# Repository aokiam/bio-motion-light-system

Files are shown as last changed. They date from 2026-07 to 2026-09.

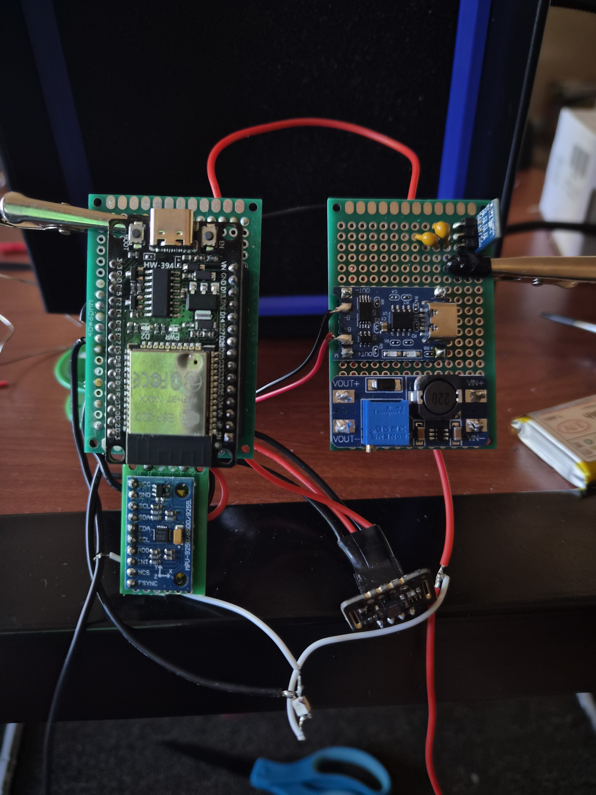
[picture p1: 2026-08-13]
hardware/images/hardware-components.jpg

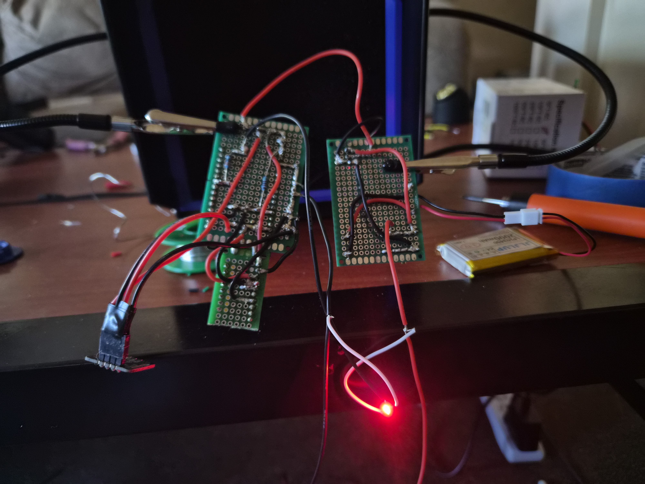
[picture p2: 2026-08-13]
hardware/images/proof-of-concept.jpg

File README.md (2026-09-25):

# BioMotion Light System
An ESP32-based wearable embedded system that visualizes physiological and motion data using addressable LEDs. The system combines heart-rate sensing, inertial measurement, Bluetooth Low Energy (BLE), and real-time LED animation to create adaptive lighting effects.

## Status
**COMPLETE**

## Features
- ESP32-WROOM-32D firmware
- BLE companion app
- Heart-rate reactive LEDs
- Motion-reactive animations
- WS2812B addressable LEDs
- Real-time sensor processing
- Modular hardware architecture

## Hardware
### Core Components
| Component | Purpose |
|---|---|
| ESP32-WROOM-32D | Main microcontroller |
| MAX30102 | Optical heart rate sensor |
| MPU6500 | 6-axis IMU |
| WS2812B LEDs | Addressable LED lighting |
| USB-C Power Bank | Portable power for ESP32 |

## Software Architecture
The firmware is organized into independent modules to simplify development and future expansion.
```
Main Loop
|
|--- Sensor Manager
|--- BLE Manager
|--- Settings Manager
|--- State Machine
|--- Animation Engine
|--- LED Driver
```

### Responsibilities
- **Sensor Manager** - Reads heart-rate and IMU data
- **BLE Manager** - Handles communication with the mobile app
- **Settings Manager** - Stores user preferences
- **State Machine** - Controls device operating modes
- **Animation Engine** - Generates LED effects from sensor data
- **LED Driver** - Updates the WS2812B LEDs

## Demo

## BOM
| Component | Quantity | Link |
|---|---|---|
| ESP32-WROOM-32D | 1 | [Amazon](amazon.com/gp/product/B0CR5Y2JVD/ref=ox_sc_saved_title_1?smid=A2Z10KY0342329&psc=1) / [Aliexpress](https://www.aliexpress.us/item/3256808317516268.html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)
| MAX30102 | 1 | [Amazon](https://www.amazon.com/AEDIKO-MAX30102-Detection-Concentration-Compatible/dp/B09LQDW27N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) / [Aliexpress](https://www.aliexpress.us/item/3256806829092762.html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)
| MPU6500 | 1 | [Amazon](https://www.amazon.com/QCCAN-GY-6500-MPU-6500-Gyroscope-Accelerometer/dp/B0B74QXZS8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) / [Aliexpress](https://www.aliexpress.us/item/3256807106311918.html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)
| WS2812B LEDs | 1 | [Amazon](https://www.amazon.com/dp/B088FJF9XD?ref=ppx_yo2ov_dt_b_fed_asin_title)
| USB-C Power Bank | 1 | [Amazon](https://www.amazon.com/dp/B0C6XK77HJ?ref=ppx_yo2ov_dt_b_fed_asin_title&th=1)
| Capacitors | Various | [Amazon](https://www.amazon.com/dp/B094HRK8QX?th=1)
| Resistors | Various | [Amazon](amazon.com/BOJACK-Values-Resistor-Resistors-Assortment/dp/B08FD1XVL6/ref=sr_1_3?crid=11U68YXQ4GGL9&dib=eyJ2IjoiMSJ9.ZA9QUhgtnvrS43dsRj2R0Cgy41Nr97HX9SyGDpZDWpPWZZPgmlStloE5j-S4aVRzhNzVbHujwhh2rykXNWfSwWtxrdj0LjP2nuBT9WeIb1yrirSbLG2rh23-9O-s8JNNv8sogRjmW4ZHQmak2ZAvcZmQZiUZCB9a84dqvmNuLrD1v7yqO8pJ9xzG38eocl9LCAgt32m8WE6QjvAYi8n43Y5nB8lfalTQB03mP4tsoRA.vj05dTqYUgw8NiO9xexmNOf0Y1FdqwWJqsNqr4UUW60&dib_tag=se&keywords=resistor+kit&qid=1784245899&sprefix=resistor+kit%2Caps%2C369&sr=8-3)
| Perfboard | 2 40x60mm and 1 20x80mm | [Amazon](amazon.com/dp/B0BWCFH57N?ref=ppx_yo2ov_dt_b_fed_asin_title)

## Future Work
- Custom PCB design
- Mobile app expansion
- Multiple synchronized systems

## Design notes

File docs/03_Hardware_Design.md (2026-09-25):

# Hardware Design
## Overview
The hardware consists of a rechargable power bank, an ESP32 microcontroller, two sensors, and an addressable LED strip.

---
## Main Components
| Component | Purpose |
|---|---|
| ESP32-WROOM-32D | Main Controller |
| MAX30102 | Heart rate sensing |
| MPU6500 | Motion sensing |
| WS2812B LEDs | Lighting |
<<<<<<< HEAD
| Power Bank | Portable power |
=======
| TP4056 | Battery charging |
| MT3608 | 5V boost converter |
| AMS 1117 | 3.3V regulator |
| LiPo Battery | Portable power |
>>>>>>> 4d88ec08d6901f317757a8ecc8b70e3ebece8073

---
## Power Architecture
```
USB-C Power Bank
  |
ESP32 USB-C Port
  | +5V
     |----- LED Strip
  | +3.3V
     |----- Sensors
```
---
## Sensor Connections
### MAX30102
- SDA -> ESP32 SDA
- SCL -> ESP32 SCL
- 3.3V
- GND

### MPU6500
- SDA -> ESP32 SDA
- SCL -> ESP32 SCL
- 3.3V
- GND

Both sensors share the same I2C bus.

---
## LED Interface
The WS2812B LED strip is driven using a single GPIO pin.

---
## Design Considerations
- Separate 5V and 3.3V rails
- Common ground throughout system
- Decoupling capacitors near every IC
- Thermal considerations during high LED brightness

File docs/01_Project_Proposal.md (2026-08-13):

# Project Proposal
## Project Title
BioMotion Light System
## Author
Allyson Aoki

---
## Overview
The BioMotion Light System is an ESP32-based embedded platform that creates dynamic LED lighting effects based on physiological and motion data. The system monitors the wearer's heart rate using a MAX30102 optical sensor and body movement using an MPU6500 inertial measurement unit (IMU). These inputs are processed in real time to generate responsive lighting animations on an addressable WS2812B LED strip.

A Bluetooth Low Energy (BLE) interface allows users to configure brightness, animation modes, color themes, and sensor sensitivity through a mobile application.

The project combines embedded firmware, power electronics, sensor integration, wireless communication, and wearable system design into a single portable platform.

---
## Objectives
### Functional Objectives
- Read heart rate continually
- Detect user movement
- Generate responsive LED animations
- Support BLE configuration
- Operate from rechargable battery power

### Educational Objectives
- Embedded firmware architecture
- I2C sensor integration
- BLE communication
- Real-time scheduling
- Power management
- Wearable electronics design

--- 
## Motivation
One of my hobbies includes cosplay, and this is planned to be implemented into a homemade cosplay headpiece. Traditional cosplay lighting systems operate generally using predefined animation sequences with limited interaction. This project explores context-aware wearable electronics that react naturally to the user's physical state, producing immersive lighting effects while remaining lightweight and portable.

---
## Expected Deliverables
- Functional embedded firmware
- Working hardware prototype
- BLE companion application
- Hardware documentation
- Wiring diagrams
- Testing documentation
- GitHub repository

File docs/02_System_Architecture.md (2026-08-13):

# System Architecture
## Overview
The system consitis of five primary subsystems:
1. Power System
2. Embedded Controller
3. Sensors
4. LED Output
5. Bluetooth Interface

```
Power Bank
    |
ESP32 3.3V Rail
 |--- MAX30102
 |--- MPU6500
 |--- BLE
 |--- WS2812B
ESP32 VIN (5V) Rail
 |--- LED Strip
```
---
## Data Flow
Heart Rate Sensor -> Sensor Manager -> State Machine -> Animation Engine -> LED Driver -> WS2812B LEDs

The IMU follows the same processing pipeline and contributes additional movement information used by the animation engine.

---
## Communication Interfaces
| Device | Interface |
|---|---|
| MAX30102 | I2C |
| MPU6500 | I2C |
| Mobile App | BLE |
| WS2812B LEDs | Single-wire data|

---
## Timing Requirements
| Task | Frequency |
|---|---|
| Heart Rate | 25Hz |
| IMU | 100 Hz |
| LED Refresh | 60 FPS |
| BLE Updates | <100 ms |

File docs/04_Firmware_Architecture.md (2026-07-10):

# Firmware Architecture
## Overview
The firmware follows a modular architecture that separates hardware drivers from application logic.
```
Main Loop
|
|--- Sensor Manager
|
|--- BLE Manager
| 
|--- Settings Manager
|
|--- State Machine
|
|--- Animation Engine
|
|--- LED Driver
```
## Modules
### Sensor Manager
Responsibilities:
- Read MAX30102
- Read MPU6500
- Filter noise measurements
- Store latest sensor values

---
### BLE Manager
Responsibilities:
- Handle BLE advertising
- Pair with phone
- Receive user settings
- Update configuration

---
### Settings Manager
Stores:
- Brightness
- Color palette
- Motion sensitivity
- Heart-rate sensitivity
- Animation mode

---
### State Machine
Controls operating modes:
- Idle
- Active
- High Motion
- Elevated Heart Rate
- Sleep

Transitions occur based on sensor thresholds

---
### Animation Engine
Uses:
- Heart rate
- Motion data
- User settings

Outputs LED frames at 60 FPS.

---
### LED Driver
Responsibilities:
- Convert animation buffer
- Send pixel data
- Maintain frame timing

--- 
### Main Execution Loop
1. Read sensors
2. Process BLE packets
3. Update state machine
4. Generate animation frame
5. Send LEDs
6. Repeat

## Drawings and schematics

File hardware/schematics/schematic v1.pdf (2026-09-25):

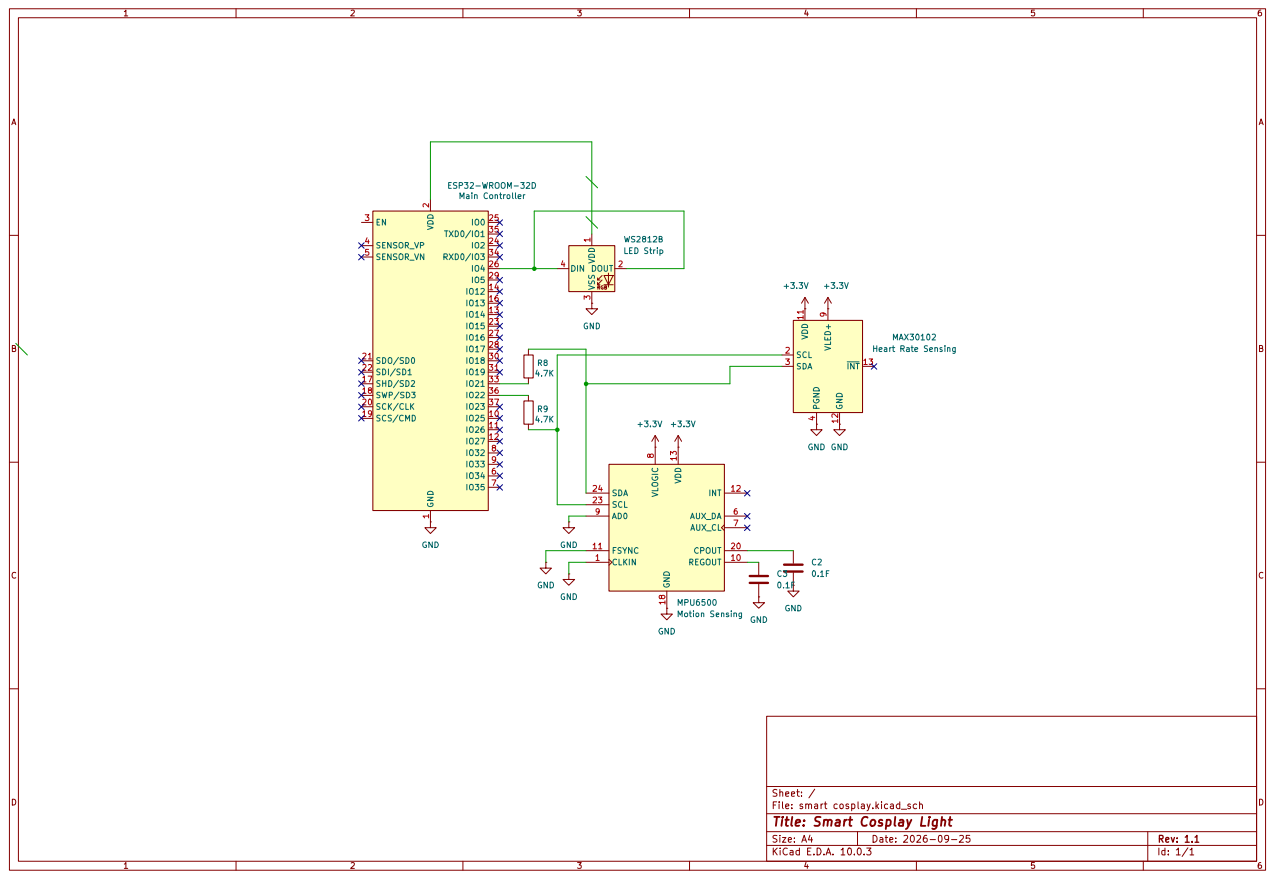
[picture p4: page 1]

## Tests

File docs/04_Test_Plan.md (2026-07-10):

# Test Plan
## Objectives
Verify that each subsystem functions independently before validating complete system integration.

---
# Unit Testing
## Heart Rate Sensor
### Procedure
Measure heart rate while resting and compare with a commercial smartwatch

**Expected error:** ±5 BPM

**Pass Criteria:** Measurements remain within tolerance

---
## IMU
Test Cases:
- Stationary
- Walking
- Quick slash
- Quick rotation

Verify acceleration and angular velocity change appropriately.

---
## LED Driver
Verify:
- All LEDs illuminate
- No flickering
- Correct colors
- Smooth animation

---
## BLE
Measure:
- Connection time
- Response latency
- Packet reliability

Target:
Settings update within 100ms.

---
# Integration Testing
Verify:

Heart rate changes -> Animation changes

Movement -> Animation changes

BLE command -> Immediate LED response

---
# Battery Testing
Measure:
- Runtime at 25%
- Runtime at 50%
- Runtime at 100%

Monitor battery voltage throughout discharge.

---
# Stress Testing
Operate continuously for:
- 30 minutes
- 1 hour
- 2 hours

Verify:
- No crashes
- Stable BLE communication
- No overheating
- Consistent sensor readings

---
# Acceptance criteria
The project is considered complete if:
- Heart rate is detected reliably
- Motion is detected accurately
- BLE communication remains stable
- LED animations remain smooth
- Battery operates safely
- System run continuously for at least two hours

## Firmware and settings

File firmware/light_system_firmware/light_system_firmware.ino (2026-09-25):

#include <Wire.h>
#include <Adafruit_NeoPixel.h>
#include "MAX30105.h"
#include "heartRate.h"
#include <BLEDevice.h>
#include <BLEServer.h>
#include <BLEUtils.h>
#include <BLE2902.h>

// PIN config
#define SDA_PIN 21
#define SCL_PIN 22
#define LED_PIN 26
#define NUM_LEDS 25

const int MPU_ADDR = 0x68;
MAX30105 particleSensor;
Adafruit_NeoPixel strip(NUM_LEDS, LED_PIN, NEO_GRB + NEO_KHZ800);

// BLE UUIDS -----------  ***match with App.jsx***
#define SERVICE_UUID            "4fafc201-1fb5-459e-8fcc-c5c9c331914b"
#define BRIGHTNESS_CHAR_UUID    "beb5483e-36e1-4688-b7f5-ea07361b26a8"
#define ANIM_MODE_CHAR_UUID     "0a3b0f1e-6b0a-4a6a-9a3a-3e6b1a2c4d5e"
#define HEART_RATE_CHAR_UUID    "6b3f1a4c-2d5e-4f6a-8b9c-1a2b3c4d5e6f"
#define COLOR_CHAR_UUID         "9c1e2f3a-4b5c-4d6e-8f7a-1b2c3d4e5f6a"
#define HR_INPUT_CHAR_UUID      "2d3e4f5a-6b7c-4d8e-9f0a-1b2c3d4e5f6b"
#define MOTION_INPUT_CHAR_UUID  "5a6b7c8d-9e0f-4a1b-8c2d-3e4f5a6b7c8d"
#define MOTION_STATE_CHAR_UUID  "3bddb61d-67dc-40e0-9da9-bc49426116e9"

BLECharacteristic *brightnessChar;
BLECharacteristic *animModeChar;
BLECharacteristic *heartRateChar;
BLECharacteristic *colorChar;
BLECharacteristic *hrInputChar;
BLECharacteristic *motionInputChar;
BLECharacteristic *motionStateChar;

bool deviceConnected = false;

// live settings; what the BLE callbacks actually change
enum AnimMode { MODE_STATIC, MODE_PULSE, MODE_SLASH, MODE_DYNAMIC };
AnimMode currentAnimMode = MODE_STATIC;

uint8_t globalBrightness = 128;
uint32_t activeColor = 0x00BFFF;
bool heartRateInputEnabled = false;
bool motionInputEnabled = false;

// heart rate detection state
const byte RATE_SIZE = 4;
byte rates[RATE_SIZE];
byte rateSpot = 0;
long lastBeat = 0;
int beatAvg = 0;
bool fingerPresent = false;

// LED state machine
enum LedState { IDLE_OFF, SEARCHING, BPM_PULSE, SLASH_ANIM, STATIC_ON };
LedState currentState = IDLE_OFF;
LedState stateBeforeSlash = IDLE_OFF;

// slash detection
float GYRO_SLASH_THRESHOLD = 300.0; //  units = deg/s
unsigned long lastSlashTime = 0;
const unsigned long SLASH_COOLDOWN = 800;

unsigned long slashStartTime = 0;
const unsigned long SLASH_STEP_MS = 40;
const unsigned long SLASH_TRAIL_MS = 1000;

// walking vs. idle detection
float motionEMA = 0.0;
const float MOTION_EMA_ALPHA = 0.2;
const float WALK_ENTER_THRESHOLD = 40.0;
const float WALK_EXIT_THRESHOLD = 20.0;
bool isWalking = false;

// ----------------- MPU6500 helpers ------------------
bool mpuPresent() {
  Wire.beginTransmission(MPU_ADDR);
  return (Wire.endTransmission() == 0);
}

void mpuWake() {
  Wire.beginTransmission(MPU_ADDR);
  Wire.write(0x6B);
  Wire.write(0x00);
  Wire.endTransmission();
}

void mpuReadGyro(float &gxd, float &gyd, float &gzd) {
  Wire.beginTransmission(MPU_ADDR);
  Wire.write(0x43);
  Wire.endTransmission(false);
  Wire.requestFrom(MPU_ADDR, 6, true);

  int16_t gx = Wire.read() << 8 | Wire.read();
  int16_t gy = Wire.read() << 8 | Wire.read();
  int16_t gz = Wire.read() << 8 | Wire.read();

  gxd = gx / 131.0;
  gyd = gy / 131.0;
  gzd = gz / 131.0;
}

bool checkForSlash() {
  float gx, gy, gz;
  mpuReadGyro(gx, gy, gz);
  float magnitude = sqrt(gx * gx + gy * gy + gz * gz);

  if (magnitude > GYRO_SLASH_THRESHOLD && millis() - lastSlashTime > SLASH_COOLDOWN) {
    lastSlashTime = millis();
    return true;
  }
  return false;
}

void updateWalkingState() {
  float gx, gy, gz;
  mpuReadGyro(gx, gy, gz);
  float magnitude = sqrt(gx * gx + gy * gy + gz * gz);

  motionEMA = (MOTION_EMA_ALPHA * magnitude) + ((1.0 - MOTION_EMA_ALPHA) * motionEMA);

  bool wasWalking = isWalking;
  if (!isWalking && motionEMA > WALK_ENTER_THRESHOLD) {
    isWalking = true;
  } else if (isWalking && motionEMA < WALK_EXIT_THRESHOLD) {
    isWalking = false;
  }

  if (isWalking != wasWalking && deviceConnected) {
    uint8_t stateByte = isWalking ? 1 : 0;
    motionStateChar->setValue(&stateByte, 1);
    motionStateChar->notify();
    Serial.print("[MOTION STATE] ");
    Serial.println(isWalking ? "Walking" : "Idle");
  }
}

// ----------------- PULSE animation ------------------
unsigned long pulsePeriod(int bpm) {
  if (bpm < 60)  return 1800;
  if (bpm < 90)  return 1200;
  if (bpm < 120) return 800;
  return 450;
}

// Applies globalBrightness as a scale on top of a base color, so the
// brightness slider affects every animation the same way.
uint32_t scaledColor(uint32_t color, float scale) {
  uint8_t r = (uint8_t)(((color >> 16) & 0xFF) * scale * (globalBrightness / 255.0));
  uint8_t g = (uint8_t)(((color >> 8) & 0xFF) * scale * (globalBrightness / 255.0));
  uint8_t b = (uint8_t)((color & 0xFF) * scale * (globalBrightness / 255.0));
  return strip.Color(r, g, b);
}

void updatePulse(unsigned long period) {
  static unsigned long activePeriod = period;
  static float phase = 0.0;
  static unsigned long lastMs = 0;

  unsigned long now = millis();
  if (lastMs == 0) lastMs = now;

  phase += (now - lastMs) / (float)activePeriod;
  lastMs = now;
  if (phase >= 1.0) phase -= 1.0;

  float wave = (sin(phase * 2 * PI) * 0.5) + 0.5;

  // Rate only changes when brightness output is 0
  if (wave <= 0.01 && globalBrightness == 0) {
    activePeriod = period;
  }

  uint32_t c = scaledColor(activeColor, wave);
  for (int i = 0; i < NUM_LEDS; i++) {
    strip.setPixelColor(i, c);
  }
}

// ----------------- SLASH animation ------------------
void startSlashAnimation() {
  stateBeforeSlash = currentState;
  currentState = SLASH_ANIM;
  slashStartTime = millis();
}

bool updateSlashAnimation() {
  unsigned long elapsed = millis() - slashStartTime;
  uint32_t c = scaledColor(activeColor, 1.0);

  for (int i = 0; i < NUM_LEDS; i++) {
    unsigned long onAt = i * SLASH_STEP_MS;
    unsigned long offAt = onAt + SLASH_TRAIL_MS;
    if (elapsed >= onAt && elapsed < offAt) {
      strip.setPixelColor(i, c);
    } else {
      strip.setPixelColor(i, 0);
    }
  }

  unsigned long lastOffAt = (NUM_LEDS - 1) * SLASH_STEP_MS + SLASH_TRAIL_MS;
  return elapsed < lastOffAt;
}

// ----------------- BLE callbacks ------------------
class ServerCallbacks : public BLEServerCallbacks {
  void onConnect(BLEServer *server) {
    deviceConnected = true;
    Serial.println("Phone connected.");
  }
  void onDisconnect(BLEServer *server) {
    deviceConnected = false;
    Serial.println("Phone disconnected, restarting advertising...");
    BLEDevice::startAdvertising(); // so it can be found again
  }
};

// Called whenever the phone writes to the brightness characteristic
class BrightnessCallbacks : public BLECharacteristicCallbacks {
  void onWrite(BLECharacteristic *characteristic) {
    String value = characteristic->getValue();
    if (value.length() > 0) {
      globalBrightness = (uint8_t)value[0];
      Serial.print("Brightness set to: ");
      Serial.println(globalBrightness);
    }
  }
};

// Called whenever the phone writes to the animation mode characteristic
class AnimModeCallbacks : public BLECharacteristicCallbacks {
  void onWrite(BLECharacteristic *characteristic) {
    String value = characteristic->getValue();
    if (value.length() > 0) {
      Serial.print("[ANIMATION] set to: ");
      Serial.println(value);
      
      if (value == "static"){
        currentAnimMode = MODE_STATIC;
      } else if (value == "pulse") {
        currentAnimMode = MODE_PULSE;
      } else if (value == "slash") {
        currentAnimMode = MODE_SLASH;
      } else if (value == "dynamic") {
        currentAnimMode = MODE_DYNAMIC;
      } else {
        Serial.println("[ANIMATION] unrecognized value, ignoring.");
      }
    }
  }
};

class ColorCallbacks : public BLECharacteristicCallbacks {
  void onWrite(BLECharacteristic *characteristic) {
    String value = characteristic->getValue();
    if (value.length() >= 3) {
      uint8_t r = (uint8_t)value[0];
      uint8_t g = (uint8_t)value[1];
      uint8_t b = (uint8_t)value[2];
      activeColor = ((uint32_t)r << 16) | ((uint32_t)g << 8) | b;
      Serial.print("[COLOR] Set to R:");
      Serial.print(r);
      Serial.print(" G:");
      Serial.print(g);
      Serial.print(" B:");
      Serial.println(b);
    } else {
      Serial.println("[COLOR] Received malformed value (expected 3 bytes), ignoring.");
    }
  }
};

class HRInputCallbacks : public BLECharacteristicCallbacks {
  void onWrite(BLECharacteristic *characteristic) {
    String value = characteristic->getValue();
    if (value.length() > 0) {
      heartRateInputEnabled = (uint8_t)value[0] != 0;
      Serial.print("[HEART RATE INPUT] ");
      Serial.println(heartRateInputEnabled ? "Enabled" : "Disabled");
    }
  }
};

class MotionInputCallbacks : public BLECharacteristicCallbacks {
  void onWrite(BLECharacteristic *characteristic) {
    String value = characteristic->getValue();
    if (value.length() > 0) {
      motionInputEnabled = (uint8_t)value[0] != 0;
      Serial.print("[MOTION INPUT] ");
      Serial.println(motionInputEnabled ? "Enabled" : "Disabled");
    }
  }
};

void setup() {
  Serial.begin(9600);
  delay(1000);
  Wire.begin(SDA_PIN, SCL_PIN);

  strip.begin();
  strip.show();

  if (!mpuPresent()) {
    Serial.println("MPU6500 not found.");
  } else {
    mpuWake();
    Serial.println("MPU6500 ready.");
  }

  if (!particleSensor.begin(Wire, I2C_SPEED_FAST)) {
    Serial.println("MAX30102 not found.");
  } else {
    particleSensor.setup();
    particleSensor.setPulseAmplitudeRed(0x0A);
    particleSensor.setPulseAmplitudeGreen(0);
    Serial.println("MAX30102 ready.");
  }

  Serial.println();
  Serial.println("Cosplay Prop BLE server starting");

  BLEDevice::init("CosplayProp");
  BLEServer *server = BLEDevice::createServer();
  server->setCallbacks(new ServerCallbacks());

  BLEService *service = server->createService(BLEUUID(SERVICE_UUID), 30);

  brightnessChar = service->createCharacteristic(
    BRIGHTNESS_CHAR_UUID, BLECharacteristic::PROPERTY_READ | BLECharacteristic::PROPERTY_WRITE);
  brightnessChar->setCallbacks(new BrightnessCallbacks());
  brightnessChar->setValue(&globalBrightness, 1);

  animModeChar = service->createCharacteristic(
    ANIM_MODE_CHAR_UUID, BLECharacteristic::PROPERTY_READ | BLECharacteristic::PROPERTY_WRITE);
  animModeChar->setCallbacks(new AnimModeCallbacks());
  animModeChar->setValue("pulse");

  heartRateChar = service->createCharacteristic(
    HEART_RATE_CHAR_UUID, BLECharacteristic::PROPERTY_READ | BLECharacteristic::PROPERTY_NOTIFY);
  heartRateChar->addDescriptor(new BLE2902());
  uint8_t initialBpm = 0;
  heartRateChar->setValue(&initialBpm, 1);

  colorChar = service->createCharacteristic(
    COLOR_CHAR_UUID, BLECharacteristic::PROPERTY_READ | BLECharacteristic::PROPERTY_WRITE);
  colorChar->setCallbacks(new ColorCallbacks());
  uint8_t initialColor[3] = {0, 80, 255};
  colorChar->setValue(initialColor, 3);

  hrInputChar = service->createCharacteristic(
    HR_INPUT_CHAR_UUID, BLECharacteristic::PROPERTY_READ | BLECharacteristic::PROPERTY_WRITE);
  hrInputChar->setCallbacks(new HRInputCallbacks());
  uint8_t hrInputDefault = 1;
  hrInputChar->setValue(&hrInputDefault, 1);

  motionInputChar = service->createCharacteristic(
    MOTION_INPUT_CHAR_UUID, BLECharacteristic::PROPERTY_READ | BLECharacteristic::PROPERTY_WRITE);
  motionInputChar->setCallbacks(new MotionInputCallbacks());
  uint8_t motionInputDefault = 1;
  motionInputChar->setValue(&motionInputDefault, 1);

  motionStateChar = service->createCharacteristic(
    MOTION_STATE_CHAR_UUID, BLECharacteristic::PROPERTY_READ | BLECharacteristic::PROPERTY_NOTIFY);
  motionStateChar->addDescriptor(new BLE2902());
  uint8_t motionStateDefault = 0; // idle
  motionStateChar->setValue(&motionStateDefault, 1);

  service->start();

  BLEAdvertising *advertising = BLEDevice::getAdvertising();
  advertising->addServiceUUID(SERVICE_UUID);
  advertising->setScanResponse(true);
  BLEDevice::startAdvertising();

  Serial.println("BLE advertising started. Look for 'CosplayProp'.");
  Serial.println();
}

void loop() {
  bool wantsHeartRate = (currentAnimMode == MODE_PULSE || currentAnimMode == MODE_DYNAMIC) && heartRateInputEnabled;
  bool wantsMotion = (currentAnimMode == MODE_SLASH || currentAnimMode == MODE_DYNAMIC) && motionInputEnabled;

  // --- Heart rate sensing, only when this mode/toggle combination wants it ---
  if (wantsHeartRate) {
    long irValue = particleSensor.getIR();
    fingerPresent = irValue > 50000;
    bool beatUpdated = false;

    if (fingerPresent && checkForBeat(irValue)) {
      long delta = millis() - lastBeat;
      lastBeat = millis();
      float bpm = 60.0 / (delta / 1000.0);
      if (bpm > 20 && bpm < 255) {
        rates[rateSpot++] = (byte)bpm;
        rateSpot %= RATE_SIZE;
        int sum = 0;
        for (byte x = 0; x < RATE_SIZE; x++) sum += rates[x];
        beatAvg = sum / RATE_SIZE;
        beatUpdated = true;
      }
    }

    // Push the current BPM to the phone once per second
    static unsigned long lastNotify = 0;
    const unsigned long MIN_NOTIFY_INTERVAL = 200;
    if (deviceConnected && beatUpdated && millis() - lastNotify > MIN_NOTIFY_INTERVAL) {
      lastNotify = millis();
      uint8_t bpmByte = (uint8_t)beatAvg;
      heartRateChar->setValue(&bpmByte, 1);
      heartRateChar->notify();
    }
  } else {
    fingerPresent = false;
    beatAvg = 0;
  }

  // --- Motion sensing, only when this mode/toggle combination wants it ---
  bool slashTriggered = false;
  if (wantsMotion && currentState != SLASH_ANIM) {
    slashTriggered = checkForSlash();
  }
  if (slashTriggered) {
    startSlashAnimation();
  }

  // --- Walk detection ---
  if (deviceConnected) {
    updateWalkingState();
  }

  // --- State transitions, skipped while a slash animation is actively playing ---
  if (currentState != SLASH_ANIM) {
    if (currentAnimMode == MODE_STATIC) {
      currentState = STATIC_ON;
    } else if (currentAnimMode == MODE_SLASH) {
      // Slash-only mode has no baseline animation - just idle off between triggers
      currentState = IDLE_OFF;
    } else {
      // Pulse and Dynamic modes both use the heart-rate baseline
      if (!fingerPresent) {
        currentState = STATIC_ON;
      } else if (beatAvg == 0) {
        currentState = SEARCHING;
      } else {
        currentState = BPM_PULSE;
      }
    }
  }

  // --- Render ---
  switch (currentState) {
    case IDLE_OFF:
      strip.clear();
      break;
    case STATIC_ON: {
      uint32_t c = scaledColor(activeColor, 1.0);
      for (int i = 0; i < NUM_LEDS; i++) {
        strip.setPixelColor(i, c);
      }
      break;
    }
    case SEARCHING:
      updatePulse(2500);
      break;
    case BPM_PULSE:
      updatePulse(pulsePeriod(beatAvg));
      break;
    case SLASH_ANIM:
      if (!updateSlashAnimation()) {
        currentState = stateBeforeSlash;
      }
      break;
  }

  strip.show();
  delay(10);
}

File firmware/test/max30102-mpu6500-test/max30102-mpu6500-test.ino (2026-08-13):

/******************************************************************************************** 
Combined connection + functionality test for MPU6500 (IMU) and MAX30102 (heart rate)
on an ESP32-WROOM-32D, sharing one I2C bus.

Wiring:
  ESP32 3V3  -> 3.3V rail
  ESP32 GND  -> GND rail
  ESP32 GPIO21 (SDA) -> SDA rail
  ESP32 GPIO22 (SCL) -> SCL rail
  5.1k pull-up: SDA rail -> 3.3V
  5.1k pull-up: SCL rail -> 3.3V
  MPU6500: VCC->3.3V, GND->GND, SCL->SCL rail, SDA->SDA rail, AD0->GND (address 0x68)
  MAX30102: VIN->3.3V, GND->GND, SCL->SCL rail, SDA->SDA rail

Required library (install via Library Manager):
  "SparkFun MAX3010x Pulse and Proximity Sensor Library"

Author: Allyson Aoki
********************************************************************************************/

#include <Wire.h>
#include "MAX30105.h"

#define SDA_PIN 21
#define SCL_PIN 22

const int MPU_ADDR = 0x68;
MAX30105 particleSensor;

bool mpuOK = false;
bool maxOK = false;

// ---------- MPU6500 helpers ----------

bool mpuPresent() {
  Wire.beginTransmission(MPU_ADDR);
  return (Wire.endTransmission() == 0);
}

void mpuWake() {
  Wire.beginTransmission(MPU_ADDR);
  Wire.write(0x6B); // PWR_MGMT_1
  Wire.write(0x00); // clear sleep bit
  Wire.endTransmission();
}

void mpuRead(float &axg, float &ayg, float &azg, float &gxd, float &gyd, float &gzd) {
  Wire.beginTransmission(MPU_ADDR);
  Wire.write(0x3B); // ACCEL_XOUT_H
  Wire.endTransmission(false);
  Wire.requestFrom(MPU_ADDR, 14, true);

  int16_t ax = Wire.read() << 8 | Wire.read();
  int16_t ay = Wire.read() << 8 | Wire.read();
  int16_t az = Wire.read() << 8 | Wire.read();
  Wire.read(); Wire.read(); // discard temperature bytes
  int16_t gx = Wire.read() << 8 | Wire.read();
  int16_t gy = Wire.read() << 8 | Wire.read();
  int16_t gz = Wire.read() << 8 | Wire.read();

  axg = ax / 16384.0; ayg = ay / 16384.0; azg = az / 16384.0;
  gxd = gx / 131.0;   gyd = gy / 131.0;   gzd = gz / 131.0;
}

// ---------- Setup ----------

void setup() {
  Serial.begin(115200);
  delay(1500); // give Serial Monitor time to connect
  Wire.begin(SDA_PIN, SCL_PIN);

  Serial.println();
  Serial.println("===== Stage 1: Connection test =====");

  // MPU6500 connection check
  Serial.print("MPU6500 at 0x68 ... ");
  mpuOK = mpuPresent();
  Serial.println(mpuOK ? "FOUND" : "NOT FOUND");
  if (mpuOK) mpuWake();

  // MAX30102 connection check
  Serial.print("MAX30102 ... ");
  maxOK = particleSensor.begin(Wire, I2C_SPEED_FAST);
  Serial.println(maxOK ? "FOUND" : "NOT FOUND");

  if (!mpuOK || !maxOK) {
    Serial.println();
    Serial.println("One or both sensors did not respond. Check:");
    Serial.println(" - SDA/SCL not swapped, correct GPIO pins in code");
    Serial.println(" - 4.7k pull-ups present on SDA and SCL");
    Serial.println(" - VCC/GND wired to every device, breadboard rows making contact");
    Serial.println(" - MPU6500 AD0 tied to GND");
    Serial.println("Halting. Fix wiring and reset the board.");
    while (1) delay(1000);
  }

  Serial.println();
  Serial.println("Both sensors found. Configuring MAX30102...");
  particleSensor.setup(0x1F, 4, 2, 100, 411, 4096); // brightness, avg, mode(Red+IR), sample rate, pulse width, ADC range

  Serial.println();
  Serial.println("===== Stage 2: Functionality test =====");
  Serial.println("Move the board to see accel/gyro change.");
  Serial.println("Rest a fingertip on the MAX30102 to see IR jump.");
  Serial.println();
}

// ---------- Loop ----------

void loop() {
  float axg, ayg, azg, gxd, gyd, gzd;
  mpuRead(axg, ayg, azg, gxd, gyd, gzd);

  long irValue = particleSensor.getIR();
  long redValue = particleSensor.getRed();

  Serial.print("Accel g(x,y,z): ");
  Serial.print(axg, 2); Serial.print(","); Serial.print(ayg, 2); Serial.print(","); Serial.print(azg, 2);

  Serial.print("  Gyro dps(x,y,z): ");
  Serial.print(gxd, 1); Serial.print(","); Serial.print(gyd, 1); Serial.print(","); Serial.print(gzd, 1);

  Serial.print("  IR: "); Serial.print(irValue);
  Serial.print(" Red: "); Serial.print(redValue);
  Serial.println(irValue > 50000 ? "  [finger detected]" : "");

  delay(200);
}

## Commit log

2026-07-13 feat: added testing functionality for I2C on MAX30102 and MPU6500
2026-08-02 feat: added images of the current hardware
2026-08-13 feat: updated docs to match design changes to project in terms of the power supply
2026-08-20 Revise milestone and hardware details in README
    Updated current milestone and hardware components in README.
2026-08-20 fix: fixed files to run npm build successfully
    [light_system_firmware.ino]
2026-09-21 fix: GATT operation queue added
    [light_system_firmware.ino]
2026-09-21 fix: variable mismatch and syntax typo
    [light_system_firmware.ino]
2026-09-21 fix: missing calls to STATIC_ON state
    [light_system_firmware.ino]
2026-09-23 fix: missing declarations of motionStateChar
    [light_system_firmware.ino]
2026-09-23 fix: wrong input in function call
    [light_system_firmware.ino]
2026-09-24 fix: reverted the pulse animation
    [light_system_firmware.ino]
2026-09-24 fix: UUID mismatch error
    [light_system_firmware.ino]
2026-09-25 cleanup: code typos, slight changes to pulse animation, and docs
    [smart cosplay.kicad_sch]
